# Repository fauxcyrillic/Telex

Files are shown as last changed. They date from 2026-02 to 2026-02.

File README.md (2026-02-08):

# Telex
Monome Teletype for the AE modular ecosystem

Ongoing project to bring the Monome Teletype module to AE Modular.

Current version requires external USB-C power to operate. Module is connected to the AE bus cable for grounding purposes only. Alternatively, the module could be housed separately and connected to the main AE rack by way of a patch cable between Telex ground and ground on the MASTER module. Either way, external power is necessary to avoid noise problems/high power draw from the large OLED display.

# Additional components required:

* general male and female pins/headers
* LEDs x 8
* 10k potentiometer
* vertical USB-A socket
* Newhaven display NHD-2.7-12864WDY3 (yellow) or NHD-2.7-12864WDW3 (white)
* Adafruit USB-C vertical breakout board
* MCP6004 x 2
* TPS2021P power switch IC
* C&K SPST – Momentary – OFF – (ON) button switch

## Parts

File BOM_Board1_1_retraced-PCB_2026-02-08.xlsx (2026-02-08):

No. | Quantity | Comment | Designator | Footprint | Value | Manufacturer Part | Manufacturer | Supplier Part | Supplier
1 | 6 | 100nF | C2,C6,C8,C9,C14,C16 | C0402 | 100nF | CL05B104KB54PNC | SAMSUNG(三星) | C307331 | LCSC
2 | 2 | 22pF | C4,C5 | C0603 | 22pF | CL10C220JB8NNNC | SAMSUNG(三星) | C1653 | LCSC
3 | 10 | 100nF | C7,C13,C18,C21,C22,C23,C37,C53,C58,C63 | C0402 | 100nF | CL05B104KO5NNNC | SAMSUNG(三星) | C1525 | LCSC
4 | 9 | 33nF | C10,C19,C20,C34,C35,C36,C40,C54,C56 | C0603 | 33nF | CL10B333KB8NNNC | SAMSUNG(三星) | C21117 | LCSC
5 | 1 | 4.7uF | C12 | C0805 | 4.7uF | CL21A475KAQNNNE | SAMSUNG(三星) | C1779 | LCSC
6 | 6 | 10uF | C15,C17,C41,C42,C64,C71 | C1206 | 10uF | CL31A106KBHNNNE | SAMSUNG(三星) | C13585 | LCSC
7 | 1 | 4.7uF | C24 | C0603 | 4.7uF | CL10A475KO8NNNC | SAMSUNG(三星) | C19666 | LCSC
8 | 3 | 2.2uF | C28,C30,C38 | C0603 | 2.2uF | CL10A225KO8NNNC | SAMSUNG(三星) | C23630 | LCSC
9 | 1 | 470pF | C29 | C0603 | 470pF | 0603B471K500NT | FH(风华) | C1620 | LCSC
10 | 4 | 2.7nF | C31,C32,C33,C39 | C0603 | 2.7nF | 0603B272K500NT | FH(风华) | C1609 | LCSC
11 | 9 | 1nF | C43,C44,C45,C46,C47,C48,C49,C50,C51 | C0402 | 1nF | 0402B102K500NT | FH(风华) | C1523 | LCSC
12 | 1 | 4.7uF | C52 | C0402 | 4.7uF | CL05A475MP5NRNC | SAMSUNG(三星) | C23733 | LCSC
13 | 1 | 100uF | C75 | CAP-SMD_BD6.3-L6.5-W6.5-LS7.0-FD | 100uF | EFVM025ADA101M0654 | FOLLON(富隆电子) | C22388021 | LCSC
14 | 2 | 33Ω | R4,R5 | R0603 | 33Ω | 0603WAF330JT5E | UNI-ROYAL(厚声) | C23140 | LCSC
15 | 5 | 10kΩ | R6,R7,R9,R71,R72 | R0402 | 10kΩ | 0402WGF1002TCE | UNI-ROYAL(厚声) | C25744 | LCSC
16 | 1 | 33kΩ | R10 | R0402 | 33kΩ | 0402WGF3302TCE | UNI-ROYAL(厚声) | C25779 | LCSC
17 | 2 | 47kΩ | R11,R12 | R0402 | 47kΩ | 0402WGF4702TCE | UNI-ROYAL(厚声) | C25792 | LCSC
18 | 4 | 39kΩ | R13,R14,R15,R16 | R0603 | 39kΩ | 0603WAF3902T5E | UNI-ROYAL(厚声) | C23153 | LCSC
19 | 12 | 22kΩ | R17,R18,R19,R20,R50,R64,R65,R66,R67,R68,R69,R70 | R0402 | 22kΩ | 0402WGF2202TCE | UNI-ROYAL(厚声) | C25768 | LCSC
20 | 9 | 1kΩ | R21,R22,R23,R24,R25,R26,R27,R28,R81 | R0402 | 1kΩ | 0402WGF1001TCE | UNI-ROYAL(厚声) | C11702 | LCSC
21 | 8 | 30kΩ | R29,R30,R31,R32,R38,R39,R40,R41 | R0603 | 30kΩ | 0603WAF3002T5E | UNI-ROYAL(厚声) | C22984 | LCSC
22 | 1 | 47kΩ | R33 | RES-ARRAY-SMD_2512-10P-L6.4-W3.1-BL | 47kΩ | 745C101473JP | CTS(西迪斯) | C1731126 | LCSC
23 | 4 | 220Ω | R34,R35,R36,R37 | R0402 | 220Ω | 0402WGF2200TCE | UNI-ROYAL(厚声) | C25091 | LCSC
24 | 2 | 0Ω | R46,R47 | R0603 | 0Ω | 0603WAF0000T5E | UNI-ROYAL(厚声) | C21189 | LCSC
25 | 2 | 2kΩ | R48,R49 | R0402 | 2kΩ | 0402WGF2001TCE | UNI-ROYAL(厚声) | C4109 | LCSC
26 | 4 | 2.2kΩ | R76,R77,R78,R79 | R0402 | 2.2kΩ | 0402WGF2201TCE | UNI-ROYAL(厚声) | C25879 | LCSC
27 | 1 | 0Ω | R80 | R0805 | 0Ω | 0805W8F0000T5E | UNI-ROYAL(厚声) | C17477 | LCSC
28 | 1 | AT32UC3B0512-A2UT | U1 | TQFP-64_L10.0-W10.0-P0.50-LS12.0-BL |  | AT32UC3B0512-A2UT | MICROCHIP(美国微芯) | C1337392 | LCSC
29 | 2 | AD5687RBRUZ | U2,U3 | TSSOP-16_L5.0-W4.4-P0.65-LS6.4-BL-1 |  | AD5687RBRUZ | ADI(亚德诺)/LINEAR | C650115 | LCSC
30 | 1 | AD7923BRUZ-REEL7 | U4 | TSSOP-16_L5.0-W4.4-P0.65-LS6.4-BL |  | AD7923BRUZ-REEL7 | ADI(亚德诺)/LINEAR(凌特) | C27818 | LCSC
31 | 2 | AMS1117-3.3 | U5,U21 | SOT-223-3_L6.5-W3.4-P2.30-LS7.0-BR |  | AMS1117-3.3 | AMS | C6186 | LCSC
32 | 1 | 12MHz | U11 | OSC-SMD_2P-L11.4-W4.7-LS12.3 | 12MHz | ECS-120-18-5PX-JES-TR | ECS | C2450088 | LCSC
33 | 9 | BAS70-04-E3-08 | U12,U13,U14,U15,U16,U17,U18,U19,U20 | SOT-23-3_L2.9-W1.6-P1.90-LS2.8-BR |  | BAS70-04-E3-08 | VISHAY(威世) | C142581 | LCSC

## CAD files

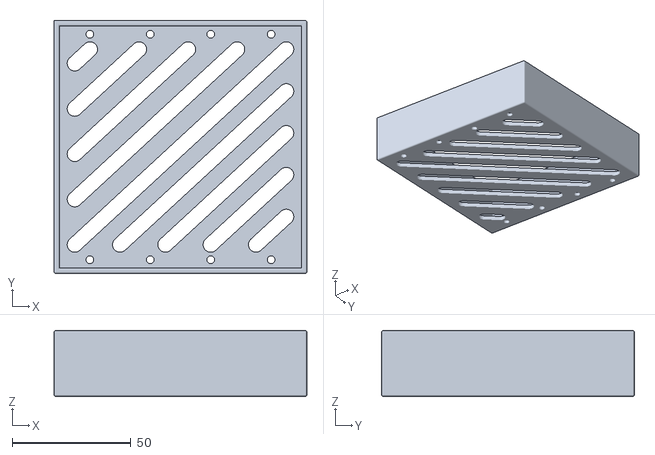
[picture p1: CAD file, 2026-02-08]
4U Rack.stl
106.4 x 106.4 x 27.8

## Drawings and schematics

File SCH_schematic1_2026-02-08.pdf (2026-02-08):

PA13 33 PA14 34 PA15 35 PA16 36 PA17 37 PB06 38 PA18 39 PA19 40 PA28 41 PA29 42 PB07 43 PA20 44 PA21 45 PA22 46 PA23 47 VDDIO 48 GND ⁴⁹ DP ⁵⁰

# GND ³V³

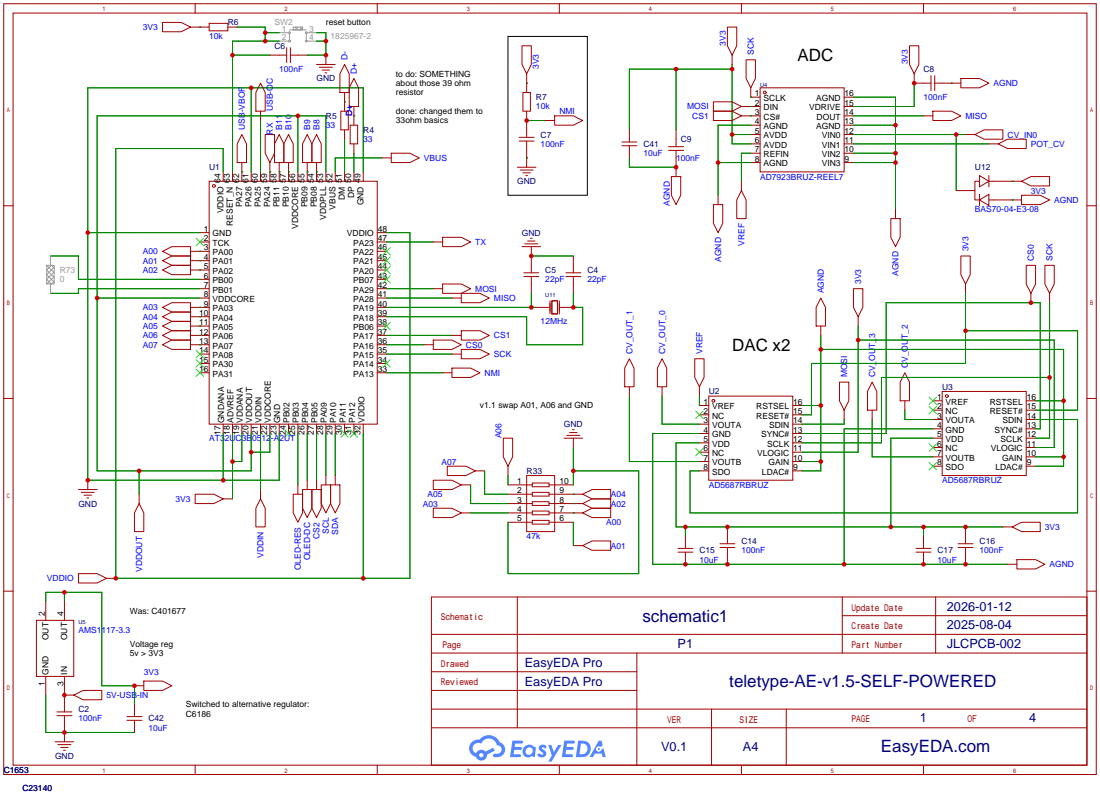
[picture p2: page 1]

VIN2 10 VIN1 11 VIN0 12 AGND 13 DOUT 14 VDRIVE 15 AGND 16

GAIN 10 VLOGIC 11 SCLK 12 SYNC# 13 SDIN 14 RESET# 15 RSTSEL 16

Switched to alternative regulator:

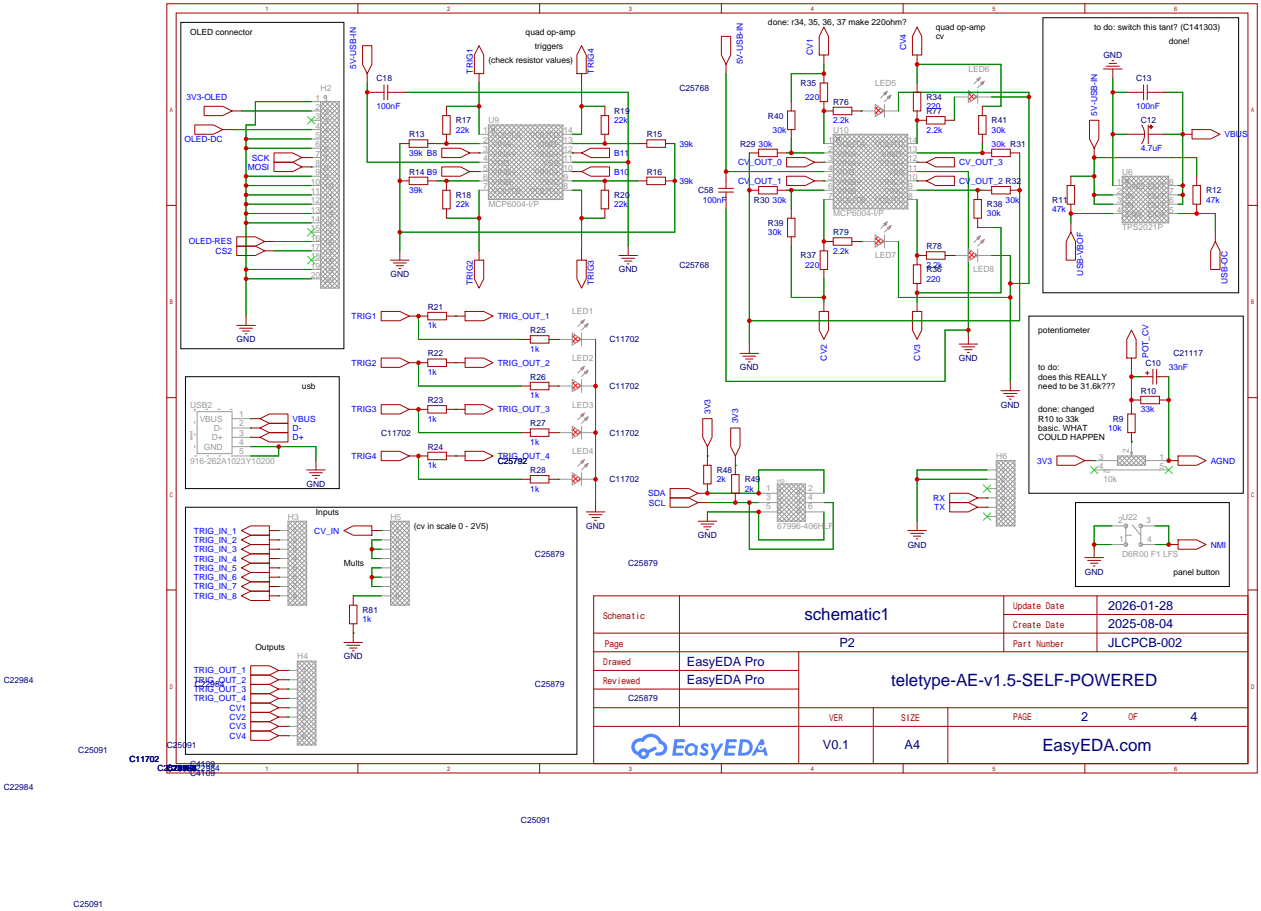
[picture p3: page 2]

to do: switch this tant? (C141303)

VINC+ 10 VSS 11 VIND+ 12 VIND- 13 VOUTD 14

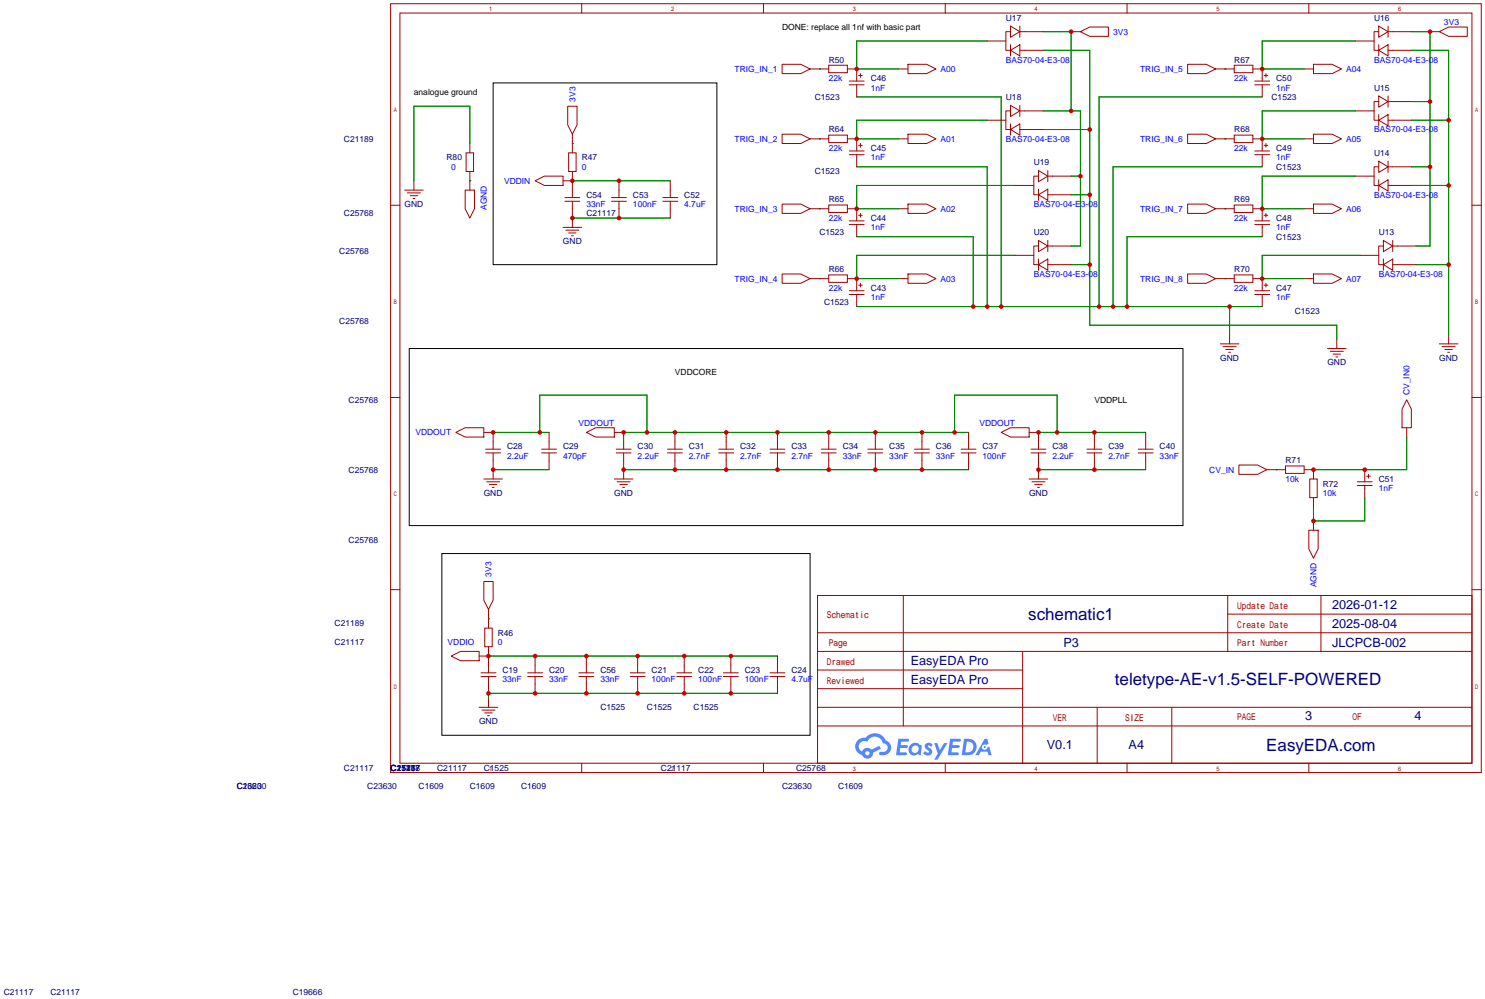
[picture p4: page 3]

DONE: replace all 1nf with basic part

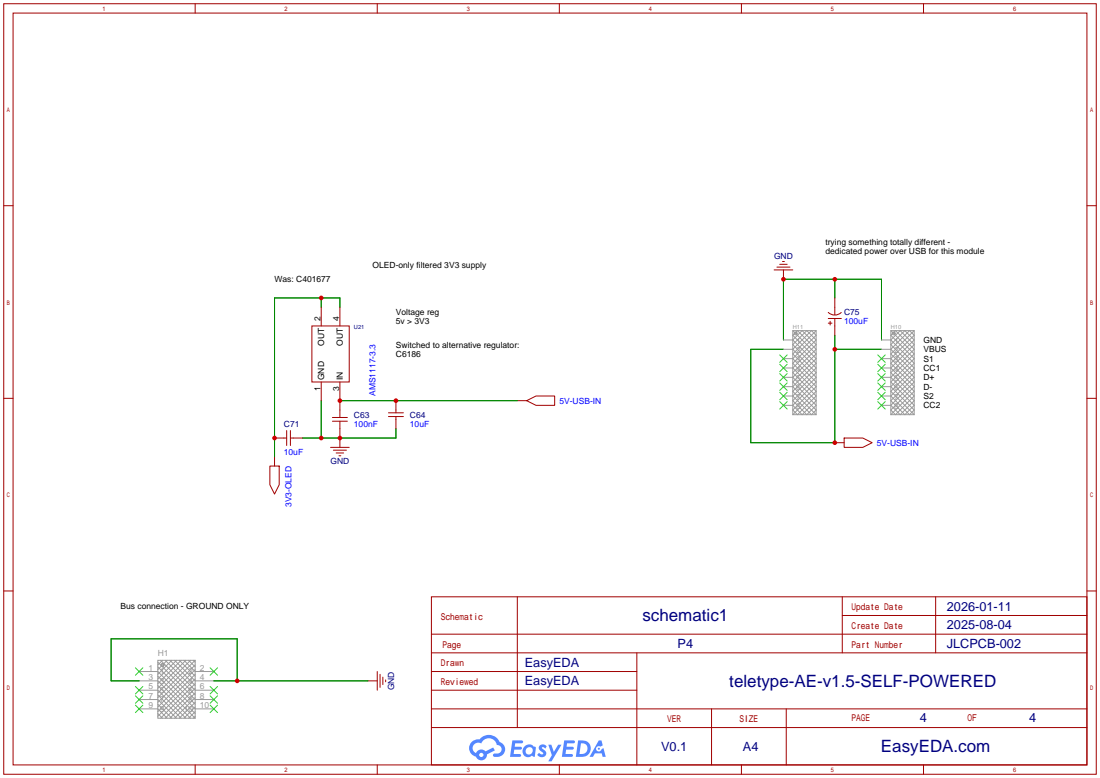
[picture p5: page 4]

trying something totally different -
dedicated power over USB for this module

OLED-only filtered 3V3 supply

Switched to alternative regulator:

Bus connection - GROUND ONLY

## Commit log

2025-04-14 Add files via upload
    Upload latest versions
    [BOM_TELEXv1_6-PCB_2024-11-30.xlsx, PickAndPlace_TELEXv1_6-PCB_2024-11-30.xlsx]
2026-02-08 Add files via upload
    Add 3D-printable 4U rack container for a stand-alone Telex module
    [4U Rack.stl]
